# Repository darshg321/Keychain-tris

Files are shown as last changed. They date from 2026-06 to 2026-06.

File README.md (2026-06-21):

# Keychain-tris

i made this project as a speedrun before the end of fallout for funsies. it is (hopefully) tetris on a keychain! how it will work is that you will be able to play tetris on the oled screen by moving the pcb around, and the imu will detect the movements. so for example, moving right will move the pieces right, and moving it down will drop it. whats great about this control method is that theres 6 axis of motion so theres plenty to work with.

the pcb has:
- an esp32c3
- a type c port for power/programming
- a lipo board
- 3v3 ldo
- and of course the imu which is an mpu 6050

## Poster (Zine)
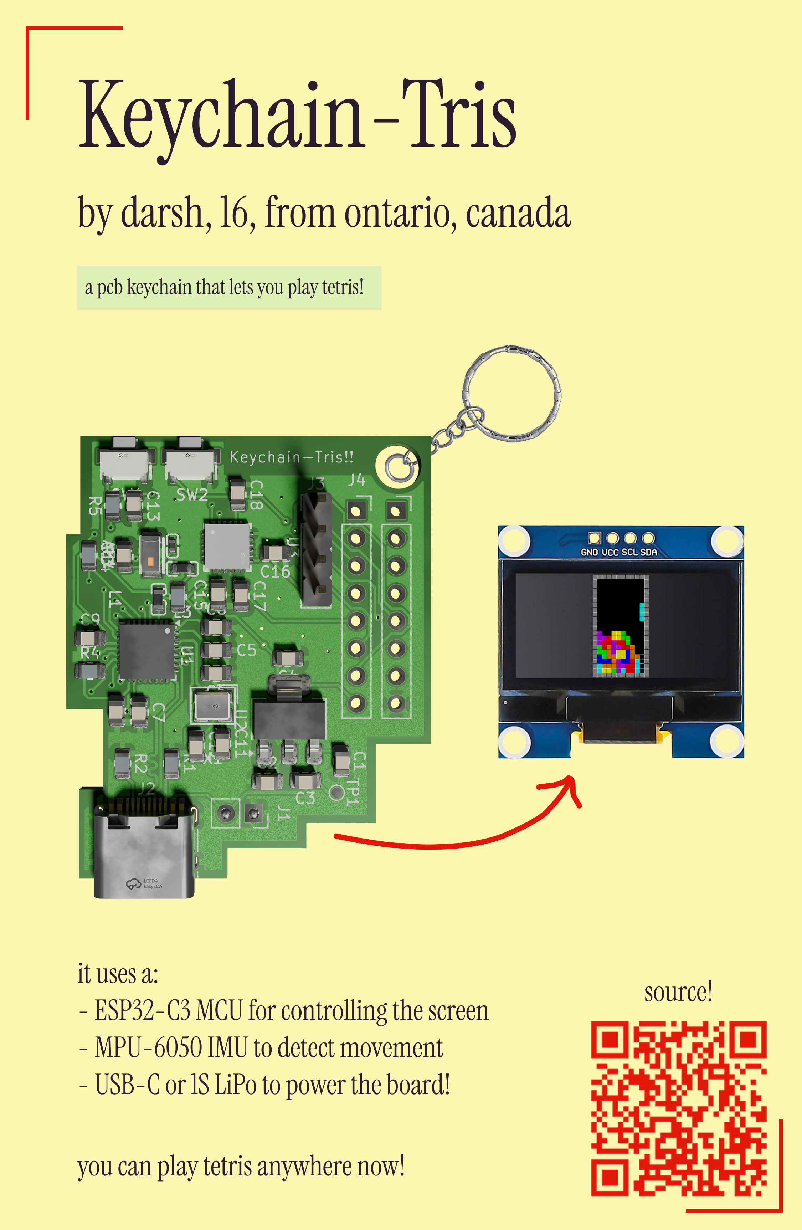
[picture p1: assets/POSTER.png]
poster


## PCB Render
render

## PCB
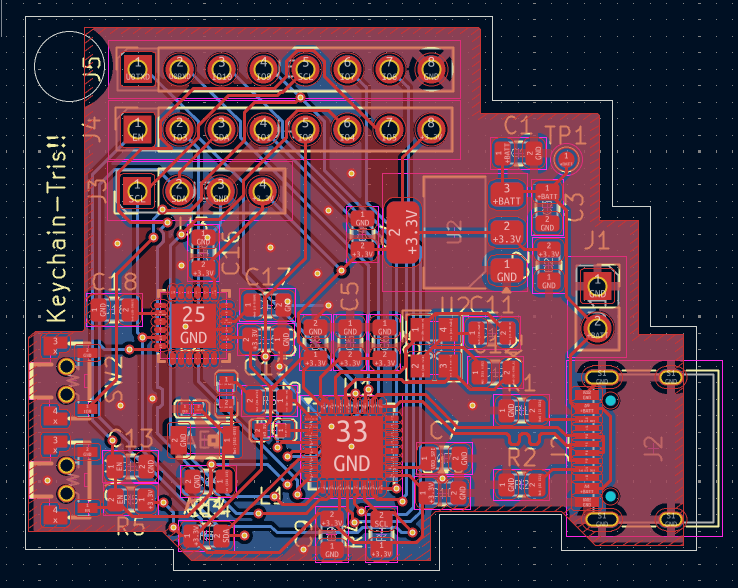
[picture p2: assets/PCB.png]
pcb


## Schematic
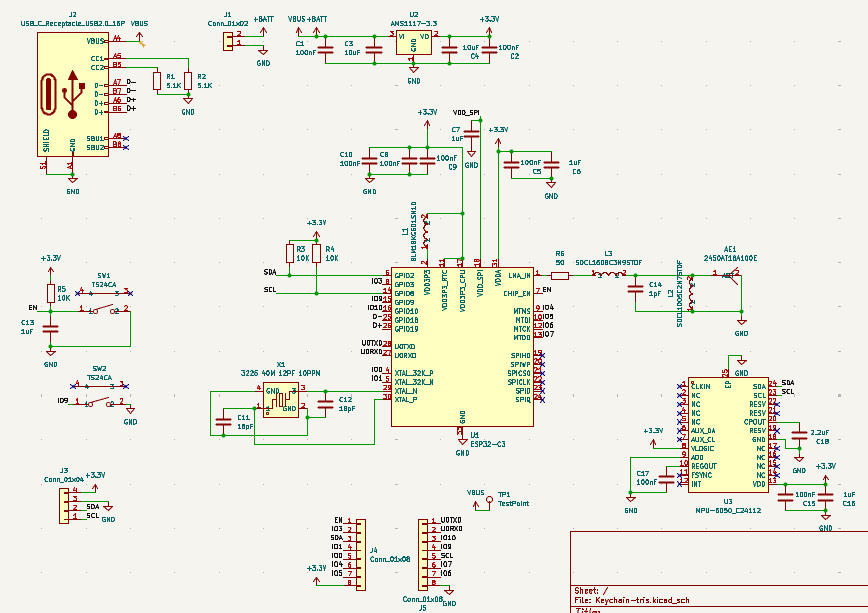
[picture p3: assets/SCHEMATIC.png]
schematic


## Assembly:
- solder on components according to pcb layout
- plug in to usb and upload firmware
- play tetris!

## BOM

|Reference |Value |Footprint |Datasheet |Qty|DNP|Exclude from BOM|Exclude from Board|
|---|---|---|---|---|---|---|---|
|AE1 |2450AT18A100E |easyeda2kicad:ANT-SMD_L3.2-W1.6 |https://lcsc.com/product-detail/RF-Antenna_JOHANSON_2450AT18A100E_2450AT18A100E_C89334.html |1  | | | |
|C1,C2,C5,C8,C9,C10,C15,C17|100nF |Capacitor_SMD:C_0805_2012Metric |~ |8  | | | |
|C3,C4 |10uF |Capacitor_SMD:C_0805_2012Metric |~ |2  | | | |
|C6,C7,C13,C16 |1uF |Capacitor_SMD:C_0805_2012Metric |~ |4  | | | |
|C11,C12 |18pF |Capacitor_SMD:C_0805_2012Metric |~ |2  | | | |
|C14 |1pF |Capacitor_SMD:C_0805_2012Metric |~ |1  | | | |
|C18 |2.2uF |Capacitor_SMD:C_0805_2012Metric |~ |1  | | | |
|J1 |Conn_01x02 |Connector_PinSocket_2.54mm:PinSocket_1x02_P2.54mm_Vertical|~ |1  | | | |
|J2 |USB_C_Receptacle_USB2.0_16P|Connector_USB:USB_C_Receptacle_HRO_TYPE-C-31-M-12 |https://www.usb.org/sites/default/files/documents/usb_type-c.zip |1  | | | |
|J3 |Conn_01x04 |Connector_PinHeader_2.54mm:PinHeader_1x04_P2.54mm_Vertical|~ |1  | | | |
|J4,J5 |Conn_01x08 |Connector_PinSocket_2.54mm:PinSocket_1x08_P2.54mm_Vertical|~ |2  | | | |
|L1 |BLM18KG601SN1D |easyeda2kicad:L0603 |https://lcsc.com/product-detail/Ferrite-Beads-And-Chips_muRata_BLM18KG601SN1D_600R-25-at100MHz_C85833.html|1  | | | |
|L2 |SDCL1005C2N7STDF |easyeda2kicad:L0402 |https://lcsc.com/product-detail/HF-Inductors_2-7nH-0-3nH_C27123.html |1  | | | |
|L3 |SDCL1608C3N9STDF |easyeda2kicad:L0603 |https://lcsc.com/product-detail/HF-Inductors_3-9nH-0-3nH_C13818.html |1  | | | |
|R1,R2 |5.1K |Resistor_SMD:R_0805_2012Metric |~ |2  | | | |
|R3,R4,R5 |10K |Resistor_SMD:R_0805_2012Metric |~ |3  | | | |
|R6 |50 |Resistor_SMD:R_0805_2012Metric |~ |1  | | | |
|SW1,SW2 |TS24CA |easyeda2kicad:SW-SMD_2P-TS24CA |https://lcsc.com/product-detail/Tactile-Switches_SHOU-HAN-TS24CA_C393942.html |2  | | | |
|TP1 |TestPoint |TestPoint:TestPoint_Pad_D1.0mm |~ |1  | | | |
|U1 |ESP32-C3 |Package_DFN_QFN:QFN-32-1EP_5x5mm_P0.5mm_EP3.7x3.7mm |https://www.espressif.com/sites/default/files/documentation/esp32-c3_datasheet_en.pdf |1  | | | |
|U2 |AMS1117-3.3 |Package_TO_SOT_SMD:SOT-223-3_TabPin2 |http://www.advanced-monolithic.com/pdf/ds1117.pdf |1  | | | |
|U3 |MPU-6050_C24112 |easyeda2kicad:QFN-24_L4.0-W4.0-P0.50-BL-EP2.7 |https://lcsc.com/product-detail/Sensors_InvenSense_MPU6050_MPU-6050_C24112.html |1  | | | |
|X1 |3225 40M 12PF 10PPM |easyeda2kicad:CRYSTAL-SMD_4P-L3.2-W2.5-BL |https://www.lcsc.com/datasheet/C5380316.pdf |1  | | | |

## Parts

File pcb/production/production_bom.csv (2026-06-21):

Designator | Footprint | Quantity | Value | LCSC Part #
AE1 | ANT-SMD_L3.2-W1.6 | 1 | 2450AT18A100E | C89334
C1, C10, C15, C17, C2, C5, C8, C9 | 0805 | 8 | 100nF
C11, C12 | 0805 | 2 | 18pF
C13, C16, C6, C7 | 0805 | 4 | 1uF
C14 | 0805 | 1 | 1pF
C18 | 0805 | 1 | 2.2uF
C3, C4 | 0805 | 2 | 10uF
J1 | PinSocket_1x02_P2.54mm_Vertical | 1 | Conn_01x02
J2 | USB_C_Receptacle_HRO_TYPE-C-31-M-12 | 1 | USB_C_Receptacle_USB2.0_16P
J3 | PinHeader_1x04_P2.54mm_Vertical | 1 | Conn_01x04
J4, J5 | PinSocket_1x08_P2.54mm_Vertical | 2 | Conn_01x08
L1 | L0603 | 1 | BLM18KG601SN1D | C85833
L2 | L0402 | 1 | SDCL1005C2N7STDF | C27123
L3 | L0603 | 1 | SDCL1608C3N9STDF | C13818
R1, R2 | 0805 | 2 | 5.1K
R3, R4, R5 | 0805 | 3 | 10K
R6 | 0805 | 1 | 50
SW1, SW2 | SW-SMD_2P-TS24CA | 2 | TS24CA | C393942
TP1 | TestPoint_Pad_D1.0mm | 1 | TestPoint
U1 | QFN-32-1EP_5x5mm_P0.5mm_EP3.7x3.7mm | 1 | ESP32-C3
U2 | SOT-223-3_TabPin2 | 1 | AMS1117-3.3
U3 | QFN-24_L4.0-W4.0-P0.50-BL-EP2.7 | 1 | MPU-6050_C24112 | C24112
X1 | CRYSTAL-SMD_4P-L3.2-W2.5-BL | 1 | 3225 40M 12PF 10PPM | C5380316

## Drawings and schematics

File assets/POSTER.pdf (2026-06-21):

# Keychain-Tris

## by darsh, 16, from ontario, canada

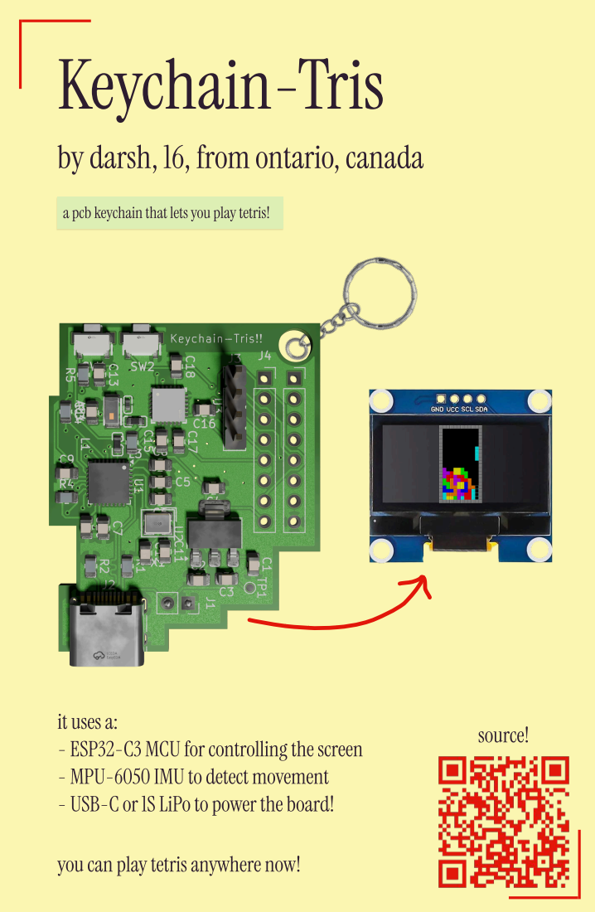
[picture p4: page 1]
source!

a pcb keychain that lets you play tetris!

it uses a:
- ESP32-C3 MCU for controlling the screen
- MPU-6050 IMU to detect movement
- USB-C or 1S LiPo to power the board!

you can play tetris anywhere now!

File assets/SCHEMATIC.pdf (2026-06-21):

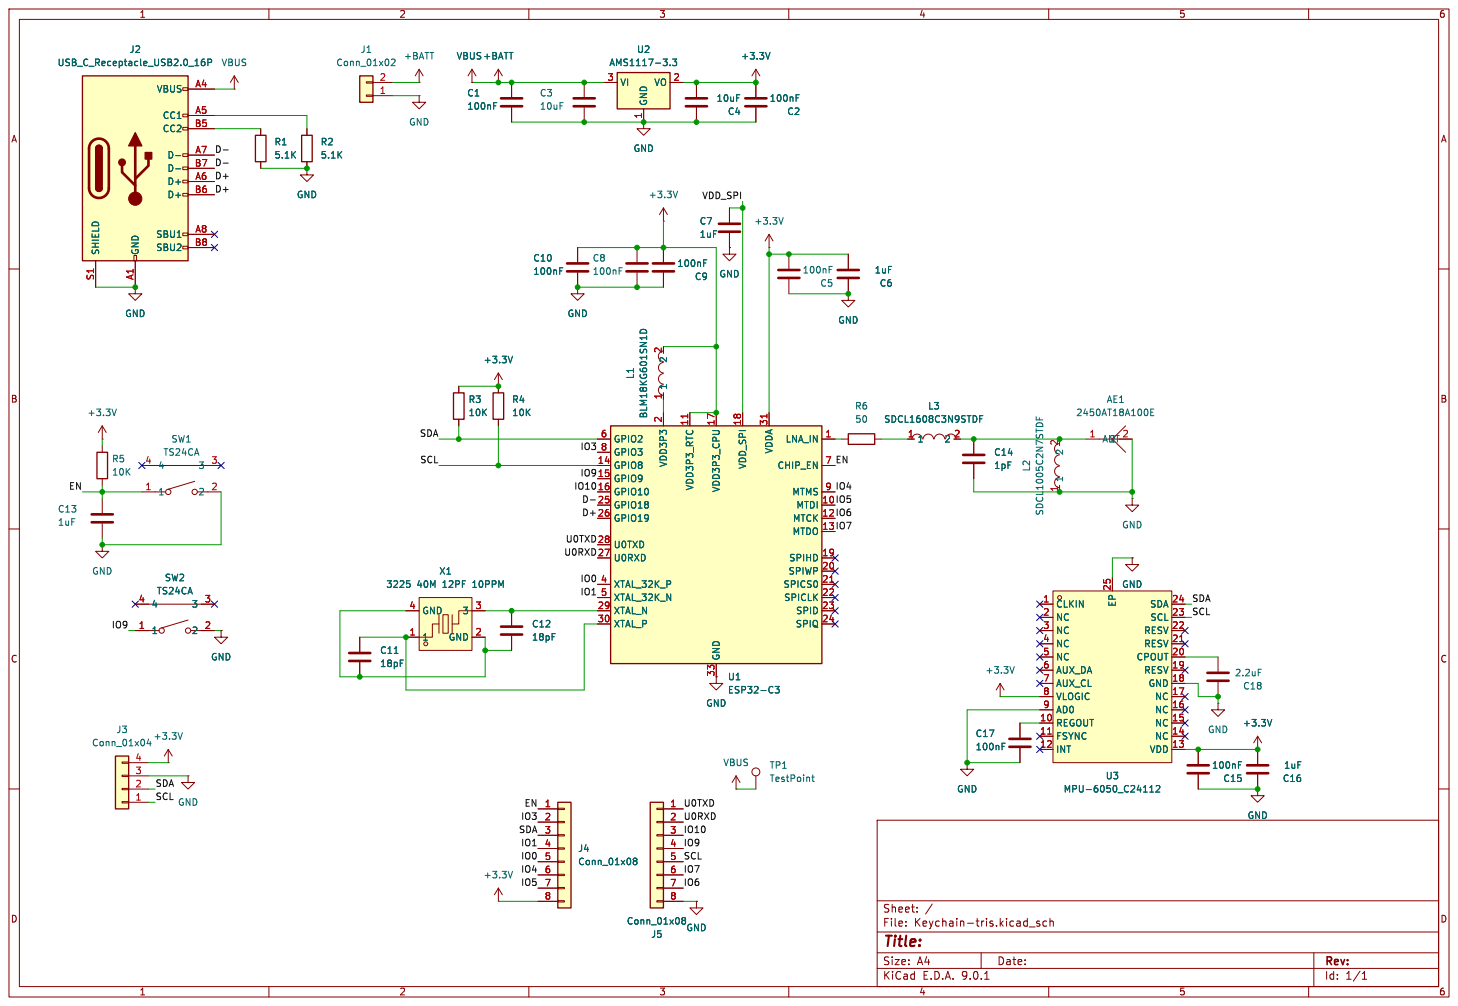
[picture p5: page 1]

Id: 1/1 Title: File: Keychain-tris.kicad_sch Sheet: /

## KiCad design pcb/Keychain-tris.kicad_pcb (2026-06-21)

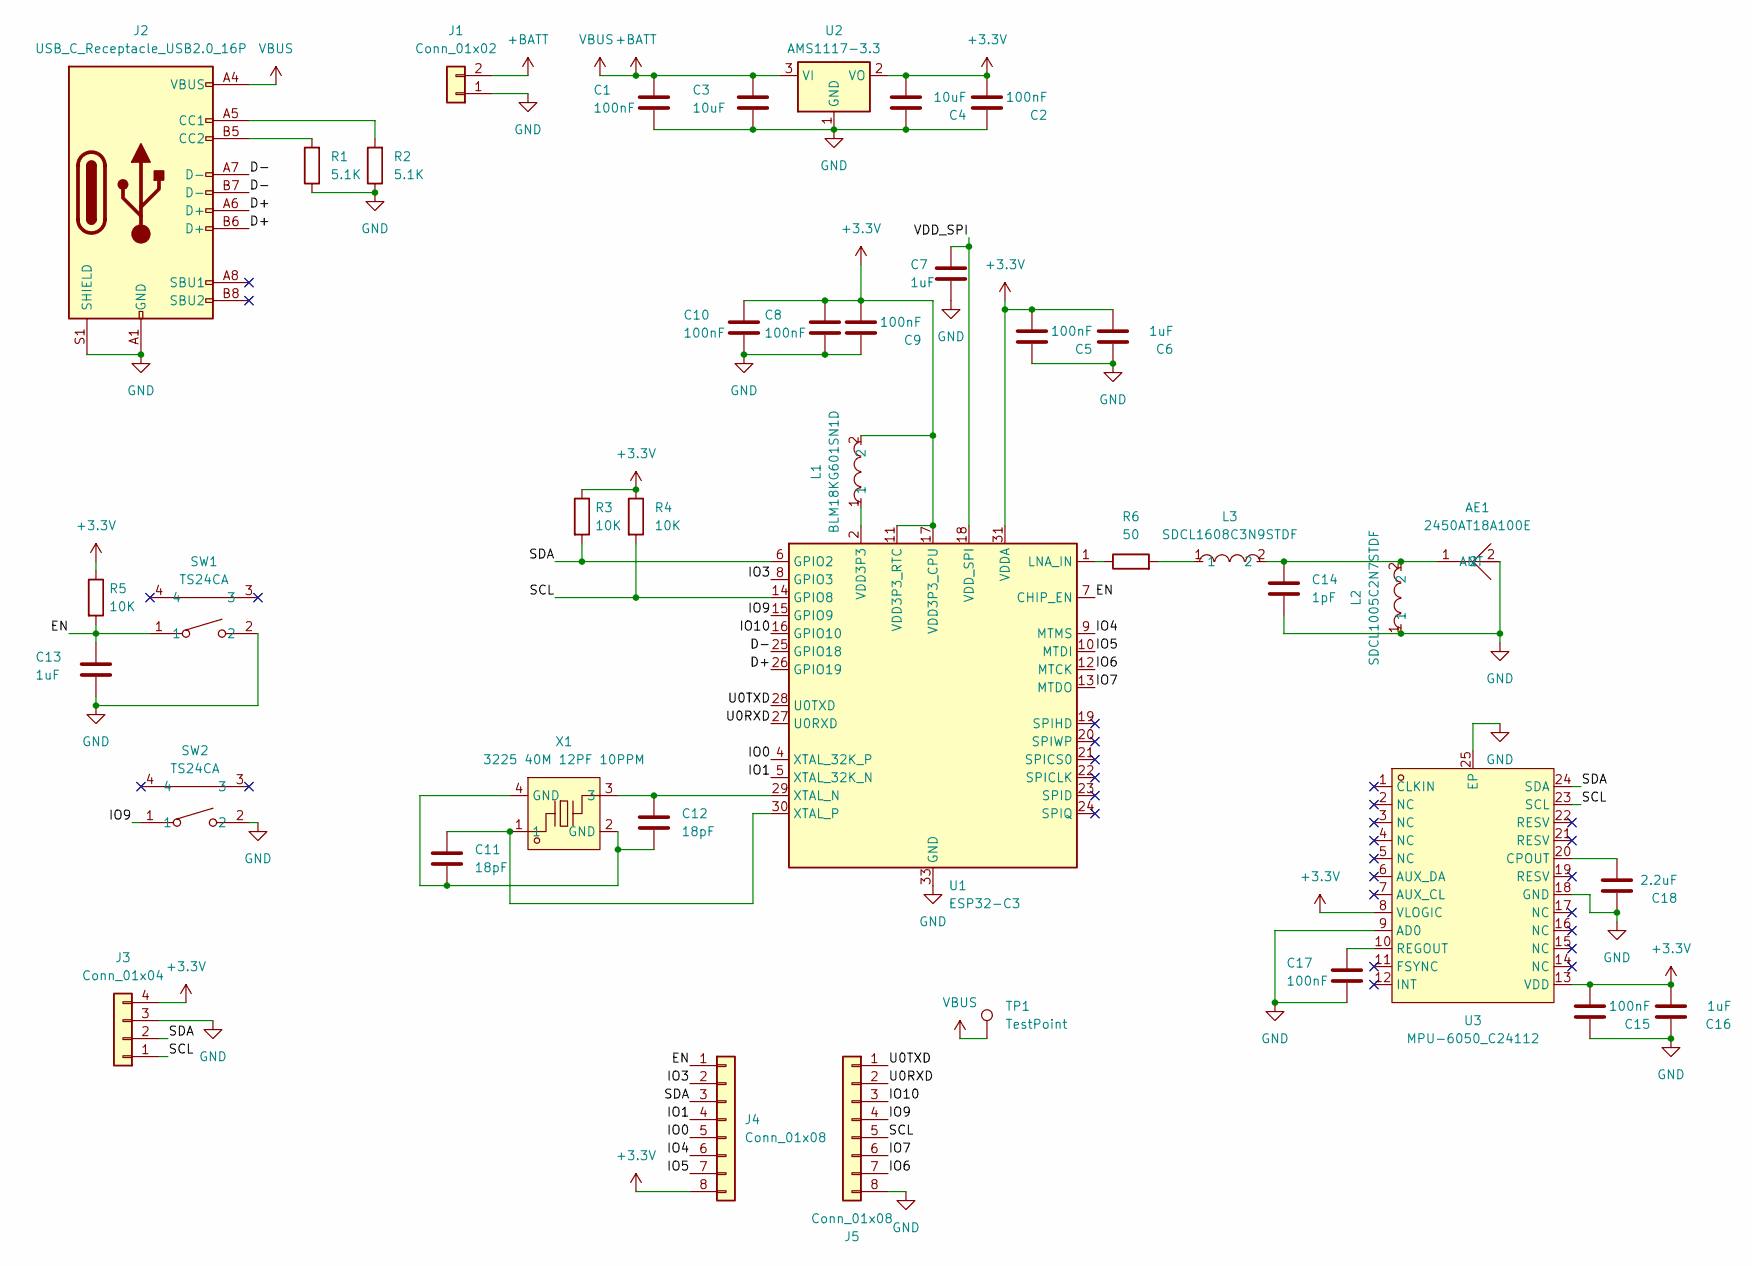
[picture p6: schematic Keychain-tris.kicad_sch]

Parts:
AE1: 2450AT18A100E; ANT-SMD_L3.2-W1.6; MPN 2450AT18A100E; LCSC Part C89334
C1, C2, C5, C8, C9, C10, C15, C17: 100nF; C_0805_2012Metric
C3, C4: 10uF; C_0805_2012Metric
C6, C7, C13, C16: 1uF; C_0805_2012Metric
C11, C12: 18pF; C_0805_2012Metric
C14: 1pF; C_0805_2012Metric
C18: 2.2uF; C_0805_2012Metric
J1: Conn_01x02; PinSocket_1x02_P2.54mm_Vertical
J2: USB_C_Receptacle_USB2.0_16P; USB_C_Receptacle_HRO_TYPE-C-31-M-12
J3: Conn_01x04; PinHeader_1x04_P2.54mm_Vertical
J4, J5: Conn_01x08; PinSocket_1x08_P2.54mm_Vertical
L1: BLM18KG601SN1D; L0603; MPN BLM18KG601SN1D; LCSC Part C85833
L2: SDCL1005C2N7STDF; L0402; MPN SDCL1005C2N7STDF; LCSC Part C27123
L3: SDCL1608C3N9STDF; L0603; MPN SDCL1608C3N9STDF; LCSC Part C13818
R1, R2: 5.1K; R_0805_2012Metric
R3, R4, R5: 10K; R_0805_2012Metric
R6: 50; R_0805_2012Metric
SW1, SW2: TS24CA; SW-SMD_2P-TS24CA; MPN TS24CA; LCSC Part C393942
TP1: TestPoint; TestPoint_Pad_D1.0mm
U1: ESP32-C3; QFN-32-1EP_5x5mm_P0.5mm_EP3.7x3.7mm
U2: AMS1117-3.3; SOT-223-3_TabPin2
U3: MPU-6050_C24112; QFN-24_L4.0-W4.0-P0.50-BL-EP2.7; MPN MPU-6050; LCSC Part C24112
X1: 3225 40M 12PF 10PPM; CRYSTAL-SMD_4P-L3.2-W2.5-BL; MPN 3225 40M 12PF 10PPM; LCSC Part C5380316

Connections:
+3.3V: C2.2, C4.2, C5.2, C6.2, C8.1, C9.2, C10.1, C15.2, C16.2, J3.4, J4.8, L1.2, R3.1, R4.1, R5.1, U1.11 (VDD3P3_RTC), U1.17 (VDD3P3_CPU), U1.31 (VDDA), U1.32 (VDDA), U2.2 (VO), U3.8 (VLOGIC), U3.13 (VDD)
+BATT: C1.1, C3.1, J1.2, J2.A4 (VBUS), J2.A9 (VBUS), J2.B4 (VBUS), J2.B9 (VBUS), TP1.1, U2.3 (VI)
/D+: J2.A6 (D+), J2.B6 (D+), U1.26 (GPIO19)
/D-: J2.A7 (D-), J2.B7 (D-), U1.25 (GPIO18)
/EN: C13.1, J4.1, R5.2, SW1.1, U1.7 (CHIP_EN)
/IO0: J4.5, U1.4 (XTAL_32K_P)
/IO1: J4.4, U1.5 (XTAL_32K_N)
/IO3: J4.2, U1.8 (GPIO3)
/IO4: J4.6, U1.9 (MTMS)
/IO5: J4.7, U1.10 (MTDI)
/IO6: J5.7, U1.12 (MTCK)
/IO7: J5.6, U1.13 (MTDO)
/IO9: J5.4, SW2.1, U1.15 (GPIO9)
/IO10: J5.3, U1.16 (GPIO10)
/SCL: J3.1, J5.5, R4.2, U1.14 (GPIO8), U3.23 (SCL)
/SDA: J3.2, J4.3, R3.2, U1.6 (GPIO2), U3.24 (SDA)
/U0RXD: J5.2, U1.27 (U0RXD)
/U0TXD: J5.1, U1.28 (U0TXD)
/VDD_SPI: C7.1, U1.18 (VDD_SPI)
GND: AE1.2, C1.2, C2.1, C3.2, C4.1, C5.1, C6.1, C7.2, C8.2, C9.1, C10.2, C13.2, C14.2, C15.1, C16.1, C17.2, C18.1, J1.1, J2.A1 (GND), J2.A12 (GND), J2.B1 (GND), J2.B12 (GND), J2.S1 (SHIELD), J3.3, J5.8, L2.1, R1.1, R2.1, SW1.2, SW2.2, U1.33 (GND), U2.1 (GND), U3.9 (AD0), U3.18 (GND), U3.25 (EP)
unnamed: AE1.1 (ANT), C14.1, L2.2, L3.2
unnamed: C11.1, C12.1, X1.2 (GND), X1.4 (GND)
unnamed: J2.A5 (CC1), R2.2
unnamed: J2.B5 (CC2), R1.2
unnamed: L1.1, U1.2 (VDD3P3), U1.3 (VDD3P3)
unnamed: L3.1, R6.2
unnamed: R6.1, U1.1 (LNA_IN)
unnamed: C12.2, U1.29 (XTAL_N), X1.3
unnamed: C11.2, U1.30 (XTAL_P), X1.1
unnamed: C18.2, U3.20 (CPOUT)
unnamed: C17.1, U3.10 (REGOUT)

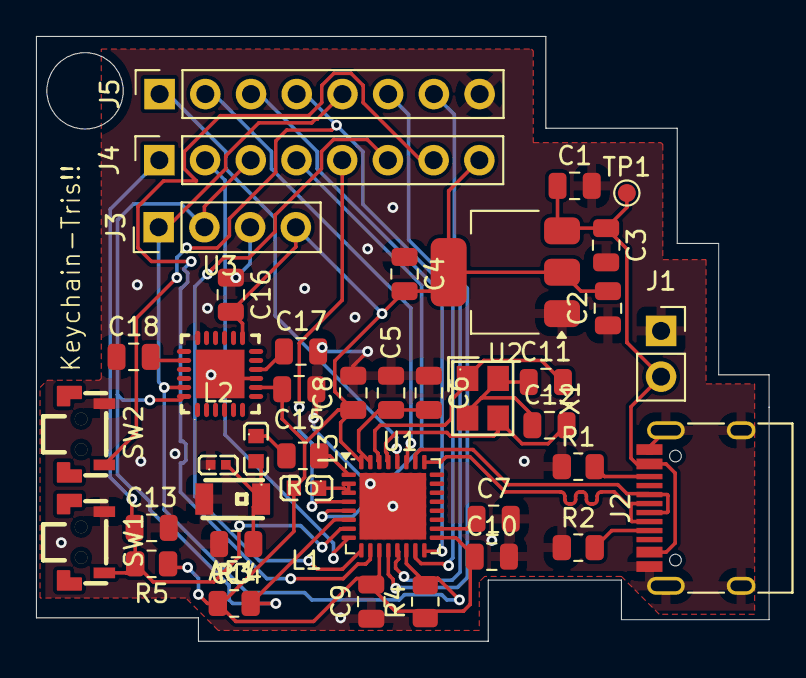
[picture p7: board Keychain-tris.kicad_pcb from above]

Board: 2 copper layers, 40.7 x 33.6 mm, 40 parts (0 on the bottom side), 31 nets.
